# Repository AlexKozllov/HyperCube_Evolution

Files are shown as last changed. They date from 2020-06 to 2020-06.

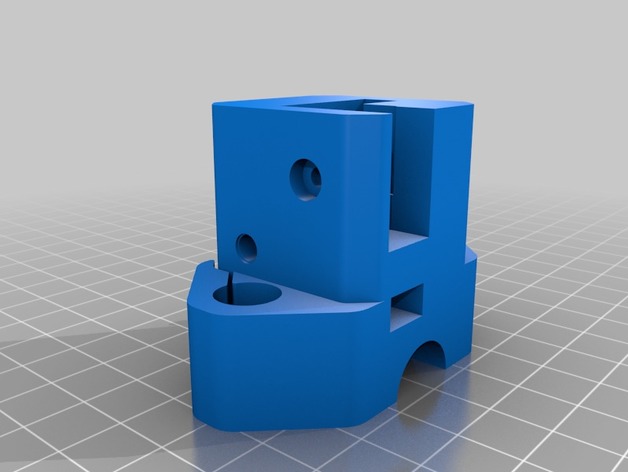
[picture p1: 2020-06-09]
images/1fd3070f1db277981bb9b3edc0ec5033_preview_featured.jpg

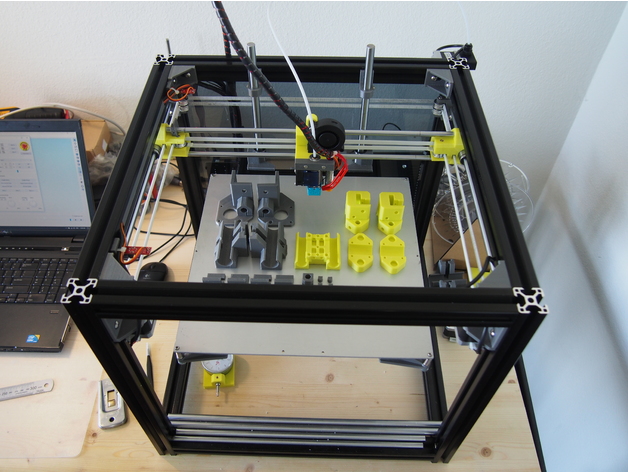
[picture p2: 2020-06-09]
images/2a23b4f932fd7e8579fa0705d6261fe2_preview_featured.JPG

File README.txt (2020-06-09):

                   .:                     :,                                          
,:::::::: ::`      :::                   :::                                          
,:::::::: ::`      :::                   :::                                          
.,,:::,,, ::`.:,   ... .. .:,     .:. ..`... ..`   ..   .:,    .. ::  .::,     .:,`   
   ,::    :::::::  ::, :::::::  `:::::::.,:: :::  ::: .::::::  ::::: ::::::  .::::::  
   ,::    :::::::: ::, :::::::: ::::::::.,:: :::  ::: :::,:::, ::::: ::::::, :::::::: 
   ,::    :::  ::: ::, :::  :::`::.  :::.,::  ::,`::`:::   ::: :::  `::,`   :::   ::: 
   ,::    ::.  ::: ::, ::`  :::.::    ::.,::  :::::: ::::::::: ::`   :::::: ::::::::: 
   ,::    ::.  ::: ::, ::`  :::.::    ::.,::  .::::: ::::::::: ::`    ::::::::::::::: 
   ,::    ::.  ::: ::, ::`  ::: ::: `:::.,::   ::::  :::`  ,,, ::`  .::  :::.::.  ,,, 
   ,::    ::.  ::: ::, ::`  ::: ::::::::.,::   ::::   :::::::` ::`   ::::::: :::::::. 
   ,::    ::.  ::: ::, ::`  :::  :::::::`,::    ::.    :::::`  ::`   ::::::   :::::.  
                                ::,  ,::                               ``             
                                ::::::::                                              
                                 ::::::                                               
                                  `,,`

https://www.thingiverse.com/thing:2254103
HyperCube Evolution by SCOTT_3D is licensed under the Creative Commons - Attribution license.
http://creativecommons.org/licenses/by/3.0/

# Summary

The HyperCube Evolution 3D Printer is a CoreXY printer inspired by the excellent HyperCube 3D Printer developed by Tech2C. The belt arrangement on that printer was the neatest CoreXY arrangement that I have seen.

I have leveraged the great work that Tech2C has done to refine his design and incorporated this with my own further development to reduce the number of printed parts and simplify the build.

Design goals for the HyperCube Evolution 3D Printer:

1. Increase the stiffness of the printer to further improve / reduce vibration artefacts.
	- 3030 extrusion used for the frame
	- 2020 extrusion used for the build platform frame
	- 8mm diameter X rails
	- 10mm diameter Y rails
	- 12mm diameter Z rails

2. Minimise the size of the printer for the chosen build volume.
	- Parametric CAD design in Autodesk Inventor
	- Excel spreadsheet provided to allow for customised printer size

The prototype printer, with a build volume of 300 x 300 x 300, met with all expectation but did show some small bed vibrations when printing at high speed due to the large bed and counter levered design. Therefore, two build options are available. A single Z axis version for smaller build platforms and a double Z axis version for larger beds or those wishing for a rock solid build platform.

The Evolution also features a quick attach X carriage to allow for interchangeable tools e.g. the extruder mount and a DTI mount for tramming the build platform.

More to come over the next few weeks as I'm awaiting parts for upgrade the prototype to use the double Z axis, and also the parts to convert my Geetech Prusa i3 into another HyperCube Evolution.

Facebook Group: https://www.facebook.com/groups/Hypercubeevolution/

<strong>Changelog:</strong>

20.04.2017 Configuration file updated, multiple size Bed Brackets added
22.04.2017 BOM added
23.04.2017 Introduction video added https://www.youtube.com/watch?v=1rctCsUGnX8&feature=youtu.be
23.04.2017 Added 4 variations of Y carriage to suit different combinations of 8mm and 10mm rails. Plus bearing clamps to suit. Note - current X carriage only suits LM8UU bearings. An adaptor will be needed to use 10mm bushings.
30.04.2017 Error found in spreadsheet which resulted in 10mm rails being 30mm too long. Version 1.2 uploaded.
09.05.2017 Version 1.1 Z Axis Linear Rail Bracket - Double Z - Left & Right. 
13.05.2017 Version 1.1 Z Nut Bracket - modified for easier assembly
13.05.2017 Z Nut Bracket for T10 leadscrew added
27.05.2017 Configuration file updated to include part print list (note that some part versions are still not available)
02.06.2017 Repetier configuration file uploaded
17.06.2017 40mm bed bracket added
17.06.2017 v1.1 versions of XY Stepper Mount and Idler Mount added which have slotted screw holes for different L brackets. v1.0 versions remain for those who don't need the slot.
17.06.2017 v1.1 of XY Stepper Mount and Idler Mount for 8mm diameter Y linear rails
18.06.2017 v1.4 configuration file added.. Thanks to Nicolas Harscoat for adding the shaft selector which then determines the part versions to be printed.
01.07.2017 CAD files uploaded for v1.0 as a pack and go. So the assembly should work. Note that some published parts are now v1.0+, but these files should get people going.
22.07.2017 Mounts for Full Graphic Controller added

<strong>BOM</strong>

<strong>Frame and linear guides</strong> – use the Excel spreadsheet to calculate the lengths required for your custom size.

3030 and 2020 extrusion
https://www.aliexpress.com/item/Customized-3030W-Aluminum-Extrusion-Profile-Free-cutting-in-any-Length-Black-Color/32799761497.html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

16 x L type bracket for 3030 extrusion
https://www.aliexpress.com/item/T-slot-L-type-90-degree-EU-standard-3030-aluminum-profile-Inside-corner-connector-bracket-with/32772827830.html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

8 x 3030 corner brackets
https://www.aliexpress.com/item/20pcs-lots-3030-corner-fitting-angle-aluminum-35-x-35-L-connector-bracket-fastener-match-use/32733275167.html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

<strong>Fasteners</strong>

M6 x 10 Button head screws - 6 off required for mounting of Stepper Motor Brackets and XY Idler Brackets

M5 x 10 Button head screws
https://www.aliexpress.com/item/100pcs-lot-M5-10-Bolt-A2-70-ISO7380-Button-Head-Socket-Screw-Bolt-SUS304-Stainless-Steel/32328885247.html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

M3 Socket head screws
https://www.aliexpress.com/item/Hex-Socket-Head-Cap-Screw-M3-Qty-90pcs-in-Box-Assortment-Kits-SUS-304-M3-4/32334431524.html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

100pcs M5 T Hammer Nuts for 3030 extrusion
https://www.aliexpress.com/item/100pcs-30-M5-hammer-nut-M5-block-t-slot-nuts-for-3030-aluminum-profile-extrusion-Slot/32688393400.html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

100pcs M5 T Hammer Nuts for 2020 extrusion
https://www.aliexpress.com/item/M5-T-Nut-Hammer-Nut-Aluminum-Connector-T-Fastener-Sliding-Nut-Nickel-Plated-Carbon-Steel-for/32619352982.html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

4 x 3mm dowel pins
https://www.aliexpress.com/item/GB119-304-Stainless-Steel-Cylindrical-Pin-Locating-Pin-M3-12/32789184323.html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

100pcs M3 5x5 Brass knurled insert
http://www.banggood.com/100pcs-M3x5x5mm-Metric-Threaded-Brass-Knurl-Round-Insert-Nuts-p-1050182.html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

<strong>Motors</strong>

1 or 2 x NEMA 17 Lead Screw M8 – length needs to be ~30mm longer than required Z travel, depending on nut type
https://www.aliexpress.com/item/New-3D-Printer-NEMA-17-Lead-Screw-300mm-Stepper-Motor-Z-Axis-3D-Printer-KIT-Step/32579962696.html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

3 x NEMA 17 42mm Stepper Motors
https://www.aliexpress.com/item/CE-certification-3pcs-4-lead-Nema17-Stepper-Motor-42-motor-D-shaft-motor-42BYGH-1-7A/32786907415.html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

<strong>Pulleys and Belts</strong>

2 x GT2 Timing Pulley (20 teeth) 5mm bore for 6mm belt
6 x GT2 Idler Pulley (20 teeth) 3mm bore
2 x GT2 Idler Pulley without teeth (20 teeth) 3mm bore
5m Polyurethane GT2 6mm belt
https://www.aliexpress.com/item/5-Meter-Polyurethane-GT2-6mm-Open-Timing-Belt-Width-6mm-GT2-2GT-Belt-For-3D-Printer/32616409980.html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

<strong>Linear Bearings</strong>

4 x LM12UU 12mm Linear Ball Bearings
4 x LM10UU 10mm Linear Ball Bearings or 2 x LM10LUU 10mm Long Linear Ball Bearings
4 x LM8UU 8mm Linear Ball Bearings

<strong>Heated Bed components</strong>

1 x Heated Bed 300x300
https://www.aliexpress.com/item/For-RepRap-3D-Prusa-Mendel-Printer-MK2A-300-300-3-0mm-Heater-Bed-RAMPS-1-4/32668984871.html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

4 or 6 x Levelling screws
https://www.aliexpress.com/item/3D-printer-Leveling-components-M3-screw-Leveling-spring-Leveling-knob-suite-free-shipping-M3-40-IMG/32562830096.html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

1 x 100kohm NTC3950 thermistor
https://www.aliexpress.com/item/1pcs-3d-printer-parts-100K-ohm-NTC-3950-Thermistors-with-cable-for-3D-Printer-Reprap-Mend/32489800025.html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

<strong>Control System</strong>

1 x 24V 400W power supply
https://www.aliexpress.com/item/Best-quality-24V-16-7A-400W-Switching-Power-Supply-Driver-for-LED-Strip-AC-100-240V/32318296978.html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

1 x RAMPS 1.4 with stepper drivers and display – NOTE: This board needs to be modified to run a 24V system. If you don’t then you will kill the Arduino Mega!
https://www.aliexpress.com/item/5pcs-A4988-Stepper-Driver-Module-with-Heatsink-1pcs-RAMPS-1-4-Controller-RAMPS1-4-LCD-12864/1869163278.html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

1 x RAMPS 1.4 fan extender module – use to run the 12V fans
https://www.aliexpress.com/item/Free-shipping-3D-Printer-Reprap-Ramps1-4-RRD-Fan-Extender-Max-20V-Fan-Expansion-Module/1804966614.html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

1 x DC-DC 24V-12V step down module
https://www.aliexpress.com/item/DC-DC-24V-18V-to-12V-3A-Step-Down-Module-MINI-Buck-Converter-Power-Supply-Circuit/32778770850.html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

1 x Arduino MEGA 2560
https://www.aliexpress.com/item/Mega-2560-CH340G-ATmega2560-16AU-Compatible-for-Arduino-Mega-2560/32517341214.html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

1 x Power expansion module (if needed)
https://www.aliexpress.com/item/for-3D-Printer-General-Add-on-Heated-Bed-Power-Expansion-Module-High-Power-Module-expansion-board/32706099435.html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

1 x 5V NPN M12 inductive sensor
https://www.aliexpress.com/item/M12-4mm-detection-5VDC-NPN-NO-LJ12A3-4-Z-BX-5V-cylinder-inductive-proximity-sensor-switch/32553311139.html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

4 x Optical end stops
https://www.aliexpress.com/item/2016-Newest-1-x-Optical-Endstop-End-Stop-Limit-Switch-Solution-for-3D-Printer-or-CNC/32656689805.html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,searchweb201602_3_10152_10065_10151_10068_10136_10137_10060_10138_10155_10062_10156_10134_10154_10056_10055_10054_10059_10099_10103_10102_10096_10148_10147_10052_10053_10142_10107_10050_10051_10084_10083_10080_10082_10081_10177_10110_10111_10112_10113_10114_10181_10037_10033_10032_10078_10079_10077_10073_10070_10123_10124,searchweb201603_2,afswitch_1,ppcSwitch_7&btsid=0a677c30-15c5-4511-bd9b-21cec7f98719&algo_expid=9458fd9d-18ca-4360-9463-2e064369527b-4&algo_pvid=9458fd9d-18ca-4360-9463-2e064369527b

<strong>Cable</strong>

5m x 24AWG 4 core UL2464 cable 
https://www.aliexpress.com/item/1M-UL-2464-2C-3C-4C-24-AWG-Multi-core-PVC-jacket-cable-Tinned-copper-wire/32781273770.html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

5m x 24AWG Red Black cable
https://www.aliexpress.com/item/IEKOV-5-M-Tinned-copper-24AWG-2-pin-Red-Black-cable-300V-PVC-insulated-wire-Electric/32649240375.html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

2m x 14AWG Silicone cable
https://www.aliexpress.com/item/14AWG-Flexible-Silicone-Wire-Cable-Soft-High-Temperature-Tinned-copper-UL-1M/32653995219.html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

5m x Servo extension cable
https://www.aliexpress.com/item/servo-JR-color-extension-cable-3p-line-futaba-jr-model-aircraft-model-wiring-Wholesale-30-core/32610086634.html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

Connectors for Stepper motors
https://www.aliexpress.com/item/20-Sets-Micro-JST-2-0-PH-6-Pin-Connector-plug-Male-Female-Crimps/32399923294.html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

# Print Settings

Printer: HyperCube Evolution
Rafts: No
Supports: Yes
Resolution: 0.2mm
Infill: 25 - 50%

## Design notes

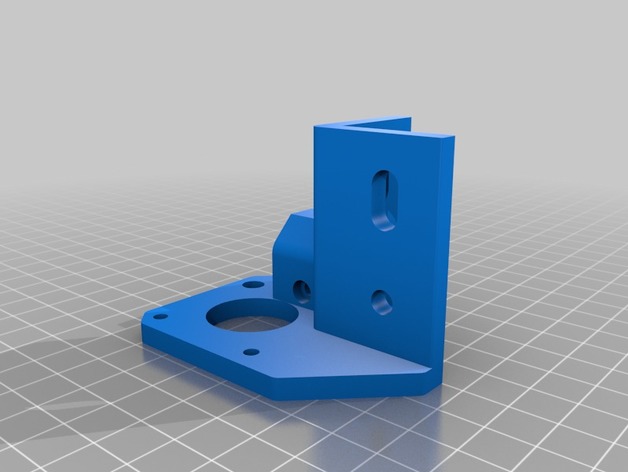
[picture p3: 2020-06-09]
images/ad542680490ceae1e7a6b8a47afab77d_preview_featured.jpg

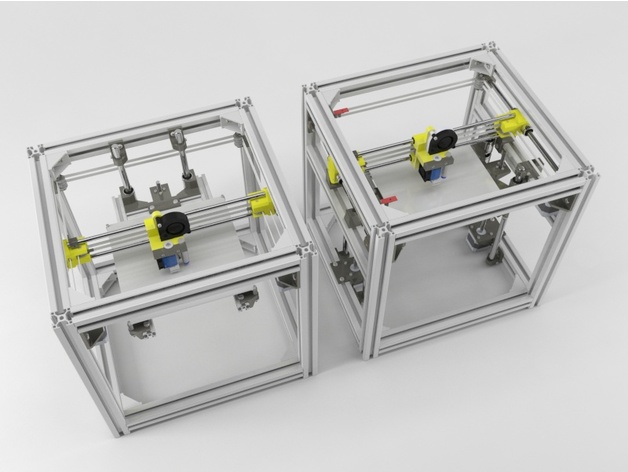
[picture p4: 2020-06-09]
images/4bb9b02da6ddbcb9a3b653392b5701b1_preview_featured.jpg

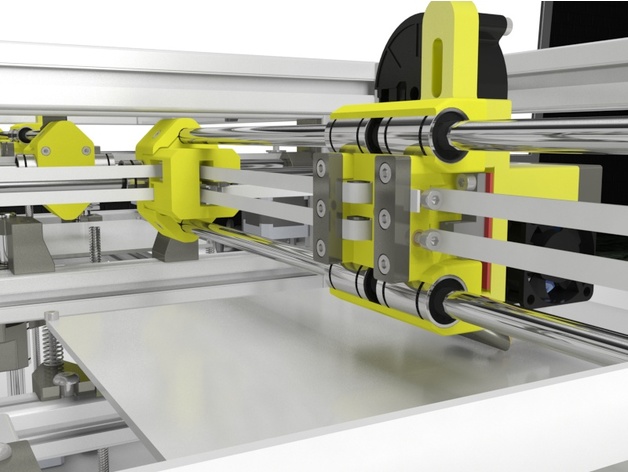
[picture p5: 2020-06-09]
images/7de90a276c049cf7b8a94b39b7449071_preview_featured.jpg

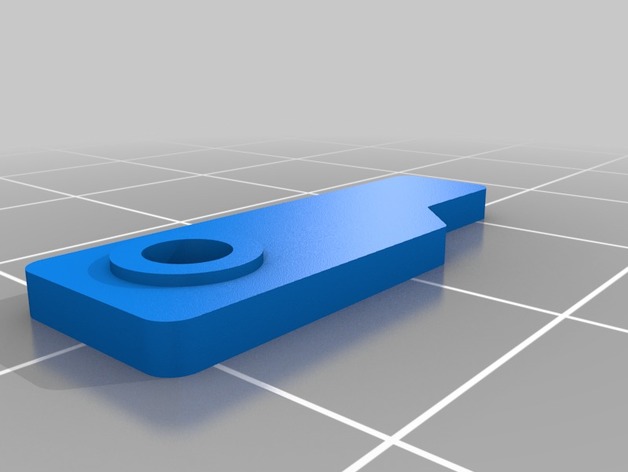
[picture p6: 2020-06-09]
images/36cfe11a45a6d4a730383c4952ed8a13_preview_featured.jpg

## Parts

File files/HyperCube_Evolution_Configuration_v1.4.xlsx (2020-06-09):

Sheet: Sheet1
Calculations - do not change
Parameter name | Equation | Unit | Design parameters
extrusion_size | 30 | mm
frame_width | 480 | mm | X Axis
frame_depth | 470 | mm | x_carriage_travel_min | 300
frame_height | 500 | mm | x_carriage_depth_rear | 14.5 | y offset from CL of x guides to rear of x carriage
platform_width | 328 | mm | x_carriage_width | 55
platform_depth | 328 | mm | x_carriage_nozzle_offset | 45.75 | y offset from CL of x guides to CL of nozzle
hole_spacing_width | 325 | mm | x_guide_spacing | 45
hole_spacing_depth | 325 | mm | x_guide_length | 450
bed_extrusion_size | 20 | mm | x_min_bed_offset | 30 |  | for dual z axis, the minimum distance between the z linear guide CL and the edge of the heated bed
bed_frame_width | 295 | mm |  |  |  |  |  | 325
bed_frame_depth | 400 | mm
bed_cl_y_offset | 216.25 | mm | Y Axis
T8_screw_length | 250 | mm | y_carriage_travel_min | 300
bracket_size | 15 | mm | y_min_offset | 31.5 | y min offset from inside of frame = width of XY motor mount
 |  |  | y_max_offset | 12 | y max offset from inside of frame = thickness of XY idler
 |  |  | y_carriage_depth | 58 | 2 x length of LM10UU bearing
 |  |  | y_carriage_width | 45 | from CL of Y axis guide to inside edge
 |  |  | y_guide_min_spacing | 445 | length of x axis guides
Build Platform | Equation | Unit | y_guide_length | 410
X width | 328 | mm
Y depth | 328 | mm | Z Axis
X spacing | 325 | mm | z_bed_travel_req | 300 |  | Note: lead screw should be this length + nut length
Y spacing | 325 | mm | z_nozzle_offset | 113.7 |  | Distance from top of frame to underside of nozzle
Bracket size | 15 | mm | z_bed_height | 68 |  | Distance from bottom of Z bearing holder to print surface
 |  |  | z_min_offset | 17 |  | Distance from bottom of frame to underside of Z bearing holder in Z Max position (bottom)
 |  |  | z_guide_diameter | 12 |  | Z linear guide diameter
 |  |  | z_guide_y_offset | 22 | CL offset from inside of frame
 |  |  | z_guide_length | 500
 |  |  |  |  |  | Single Z | Double Z
 |  |  | min_frame_width | 475 |  | 475 | 462
 |  |  | min_frame_depth | 463 |  | 463 | 388
 |  |  | min_frame_height | 498.7
 |  |  | min_bed_frame_width |  |  | 295 | 415
 |  |  | min_bed_frame_depth |  |  | 400 | 295
 |  |  | bed_mounting_width | 0 |  | 325 | 325
 |  |  | bed_mounting_depth | 0 |  | 325 | 325
 |  |  |  | 0

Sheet: Configuration
HyperCube
Evolution |  |  |  |  |  |  | Configurator | v1.4 | Build platform data
 |  |  |  |  |  |  |  |  |  | Dimensions |  | Mounting Holes
 |  |  |  |  |  |  |  |  | Name | X width | Y depth | X spacing | Y spacing
 |  |  |  |  |  |  |  |  | Mk2 Heat Bed | 214 | 214 | 210 | 210 | <- Minimum supported size. Do not change
 |  |  |  |  |  |  |  |  | Mk2A 300x300 (https://www.aliexpress.com/item/For-RepRap-3D-Prusa-Mendel-Printer-MK2A-300-300-3-0mm-Heater-Bed-RAMPS-1-4/32668984871.html) | 328 | 328 | 325 | 325
 |  |  |  |  |  |  |  |  | Custom | 300 | 300 | 290 | 290
Min. Build Volume / Travel |  |  |  |  | Build Platform |  | Z Axis
 | X | 300 | mm |  | Mk2A 300x300 | <- Select | Single | <- Select | Build platform mounting bracket data
 | Y | 300 | mm |  | Bed_bracket_15 | <- Select
 | Z | 300 | mm |  | Bracket selection Ok |  |  |  |  | Dimension
 |  |  |  |  |  |  |  |  | Name | offset
 |  |  |  |  | Shafts |  |  |  | Bed_bracket_15 | 15
 |  |  |  | X axis | Diam 8 | <- Select | Thanks to Nicolas Harscoat |  | Bed_bracket_20 | 20
 |  |  |  | Y axis | Diam 8 | <- Select | for the part selector |  | Bed_bracket_25 | 25
 |  |  |  | Z axis | Diam 12 | <- Select |  |  | Bed_bracket_30 | 30
 |  |  |  |  |  |  |  |  | Bed_bracket_45 | 45
 | BOM - Extrusions and linear guides
Item |  | Length | Unit | Qty | Note
3030 Extrusion |  | 420 | mm | 4 | Frame X extrusion
 |  | 410 | mm | 4 | Frame Y extrusion
 |  | 500 | mm | 4 | Frame Z extrusion
2020 Extrusion |  | 255 | mm | 1 | Bed frame X extrusion
 |  | 400 | mm | 2 | Bed frame Y extrusion
Diam 8 | Shaft | 450 | mm | 2 | X axis linear guide
Diam 8 | Shaft | 410 | mm | 2 | Y axis linear guide
Diam 12 | Shaft | 500 | mm | 2 | Z axis linear guide
Diam 8
Diam 10
Diam 12
Single
Double

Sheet: Print List
HyperCube | Printed part quantities
Evolution | All versions | X Axis Versions | Y Axis Versions | Z Axis Versions | Notes
Printed Part Name |  | Diam 8 | Diam 8 | Single
X-Carriage | 1
Belt_Clamp | 2
Belt_Tensioner | 4
Duct | 1
Extruder_Mount | 1
Retainer | 1
T_Slot_Cover | As needed
X_End_Stop_Flag | 2
XY_Idler_Mount_Left
XY_Idler_Mount_Left_yDia8 |  |  | 1
XY_Idler_Mount_Right
XY_Idler_Mount_Right_yDia8 |  |  | 1
XY_Stepper_Mount Left
XY_Stepper_Mount Left_yDia8 |  |  | 1
XY_Stepper_Mount Right
XY_Stepper_Mount Right_yDia8 |  |  | 1
Y_Carriage_Clamp_LM8UU |  |  | 2
Y_Carriage_Clamp_LM10UU
Y_Carriage_xDia8_LM8UU |  | 2
Y_Carriage_xDia8_LM10UU
Y_Carriage_xDia10_LM8UU
Y_Carriage_xDia10_LM10UU
Y_End_Stop_Bracket | 2
Y_End_Stop_Flag | 1
Z_Axis_Bearing_Holder |  |  |  | 2
Z_Axis_Linear_Rail_Bracket_-_Left |  |  |  | 2
Z_Axis_Linear_Rail_Bracket_-_Right |  |  |  | 2
Z_Axis_Linear_Rail_Bracket_-_Double_Z_-_Left
Z_Axis_Linear_Rail_Bracket_-_Double_Z_-_Right
Z_Motor_Mount |  |  |  | 1
Z_Nut_Braket |  |  |  | 1

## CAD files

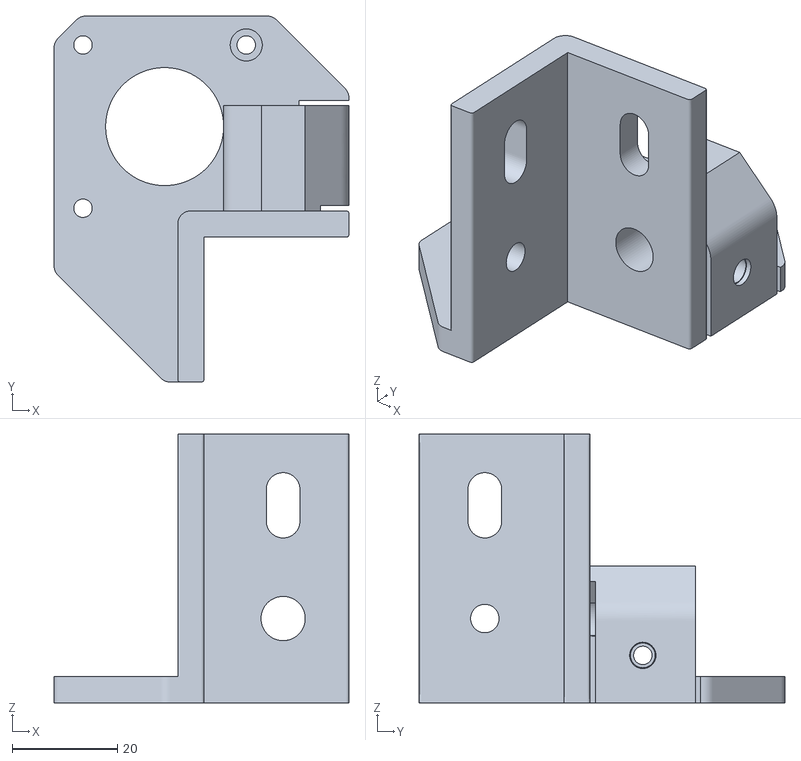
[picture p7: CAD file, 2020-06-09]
files/XY_Stepper_Mount_-_Right_yDia8_-_1.1.stl
56.0 x 69.5 x 51.0

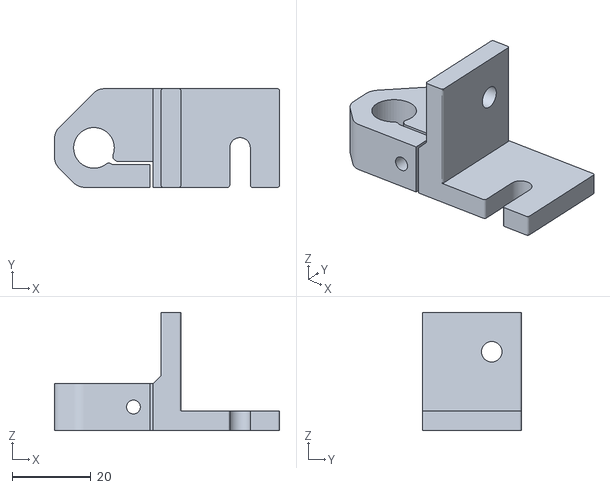
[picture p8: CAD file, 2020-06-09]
my_files/my_files_2_part/Z_Axis_Linear_Rail_Bracket_-_Right_2.0.stl
57.0 x 25.0 x 30.0

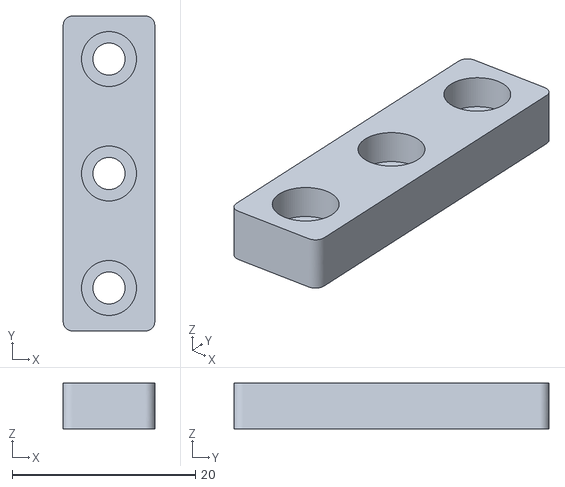
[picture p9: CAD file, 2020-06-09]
my_files/my_XYZ_2_part/Belt_Clamp_1.0.stl
10.0 x 34.4 x 5.00

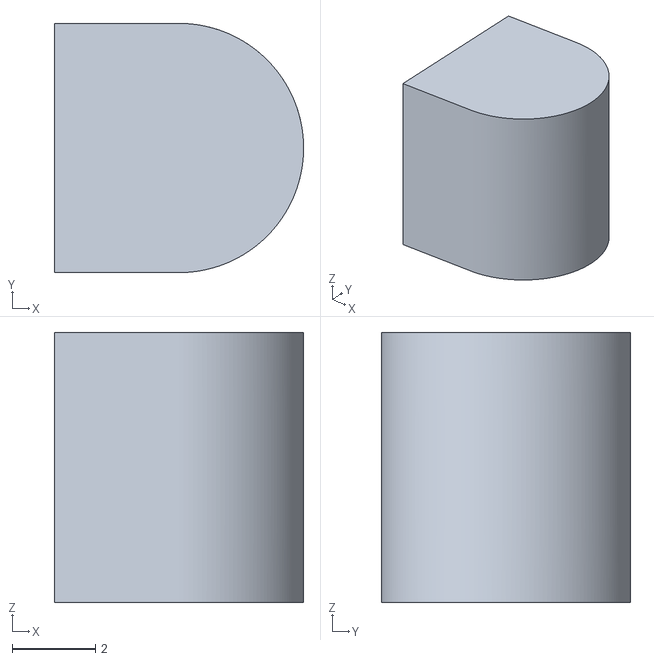
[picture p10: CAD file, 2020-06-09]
my_files/my_XYZ_3_part/Belt_Tensioner_1.0_______(_3X_).stl
6.00 x 6.00 x 6.50

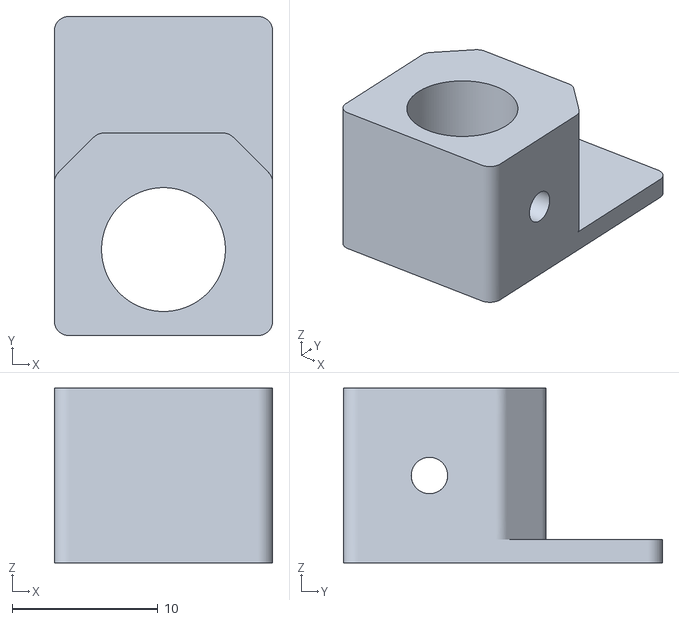
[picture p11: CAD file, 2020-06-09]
my_files/print_unchanged/Y_End_Stop_Flag_1.0.stl
15.0 x 21.9 x 12.0

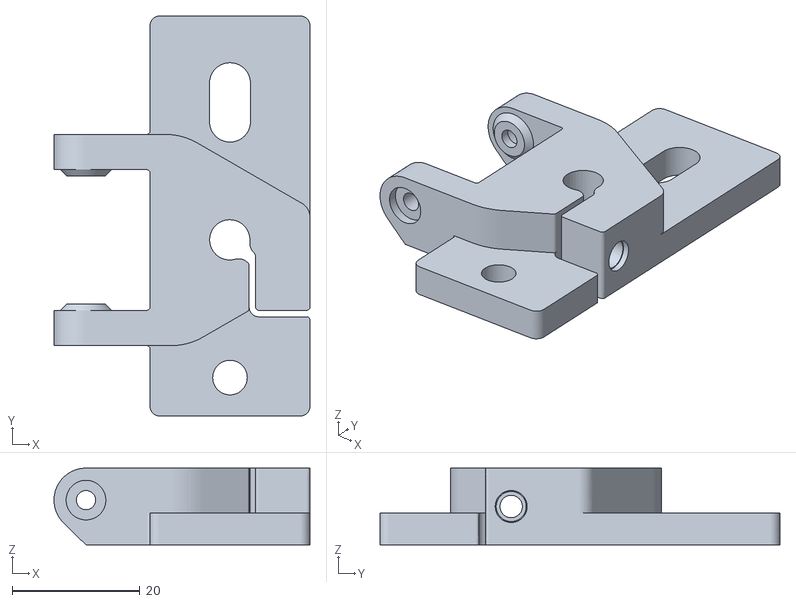
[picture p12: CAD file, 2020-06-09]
my_files/XY_Idler_Mount_-_Right_-_2.0.stl
40.0 x 62.5 x 12.0

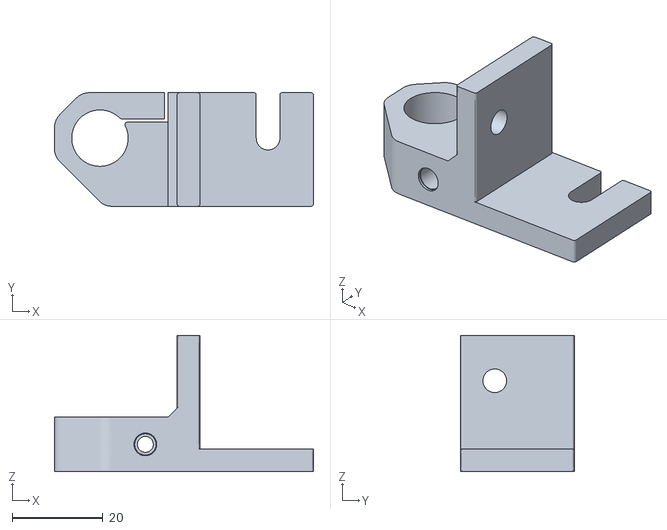
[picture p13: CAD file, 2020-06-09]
my_files/надо изменить/Z_Axis_Linear_Rail_Bracket_-_Left_1.0.stl
57.0 x 25.0 x 30.0

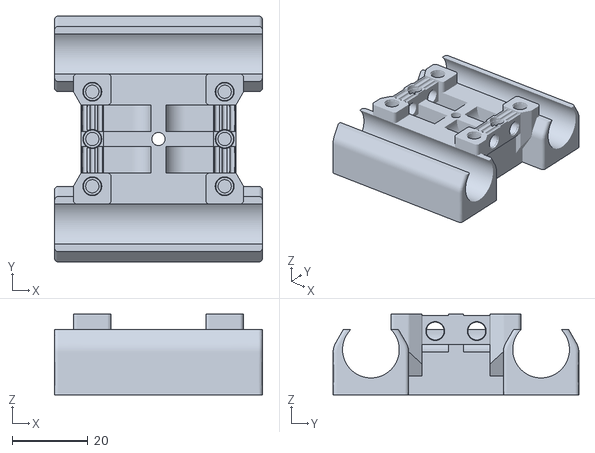
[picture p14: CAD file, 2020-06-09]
my_files/my_files_2_part/X_Carriage_1.0.stl
55.0 x 65.0 x 21.4

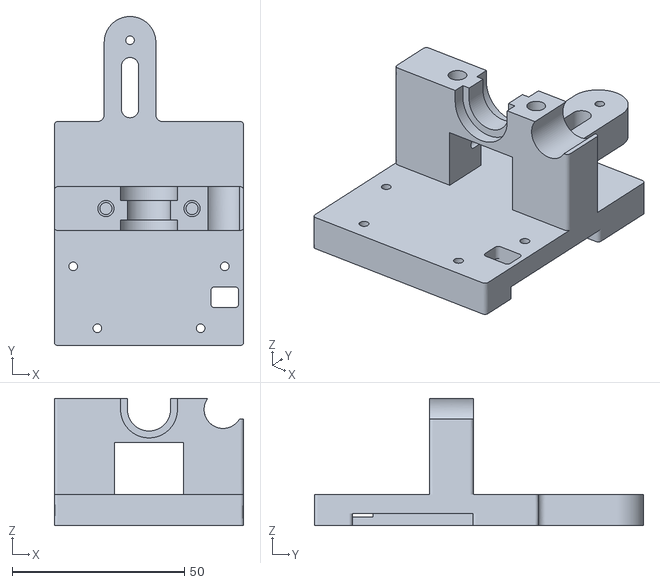
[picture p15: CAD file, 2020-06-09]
my_files/my_XYZ_2_part/Extruder_Mount_1.0.stl
55.0 x 95.5 x 37.0

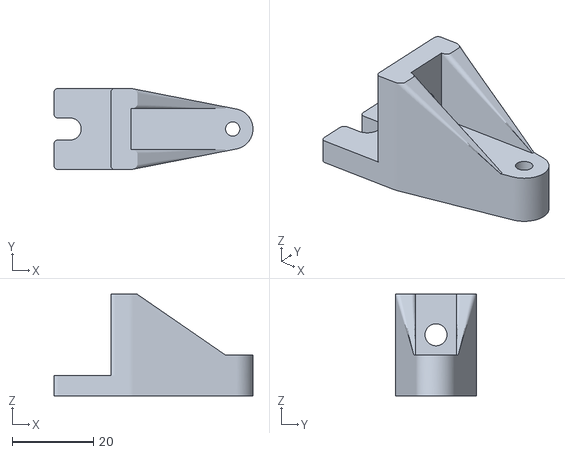
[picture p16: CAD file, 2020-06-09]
my_files/my_XYZ_3_part/Bed_Bracket_30_1.0_____(X3).stl
49.0 x 20.0 x 25.0

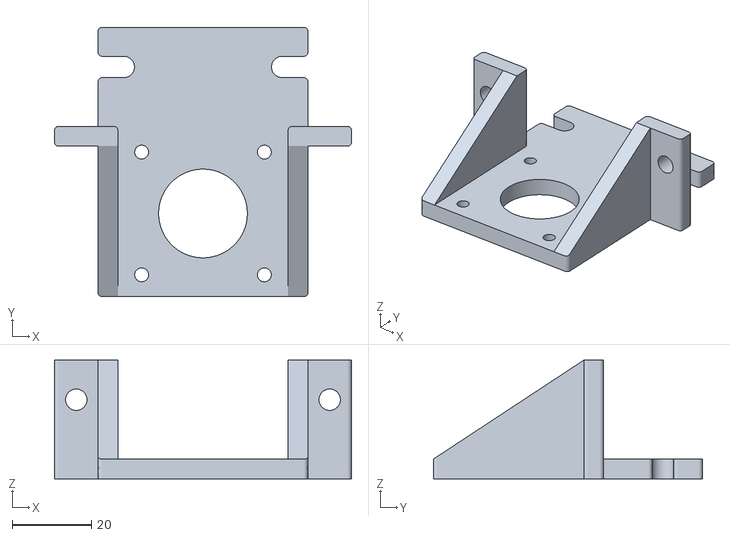
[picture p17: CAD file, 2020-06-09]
my_files/print_unchanged/Z_Motor_Mount_1.0.stl
75.0 x 68.0 x 30.0

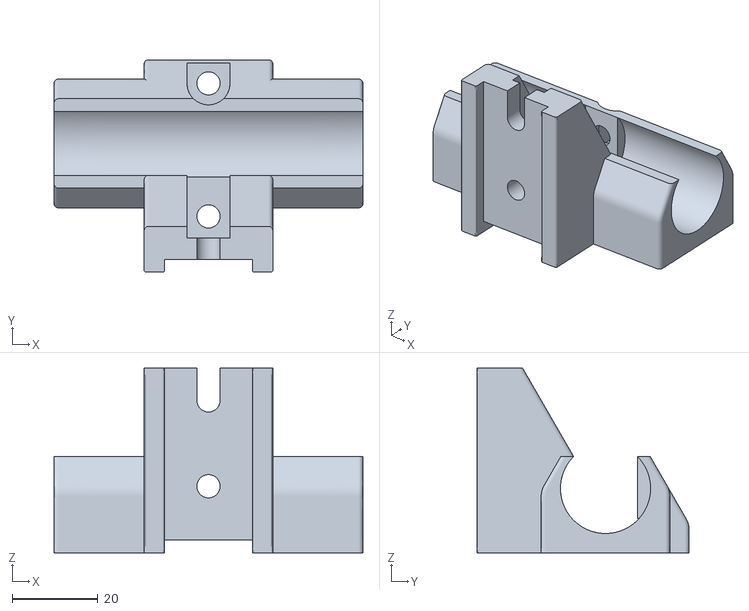
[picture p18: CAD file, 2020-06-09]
my_files/надо изменить/Z_Axis_Bearing_Holder_1.0.stl
72.0 x 49.5 x 43.0

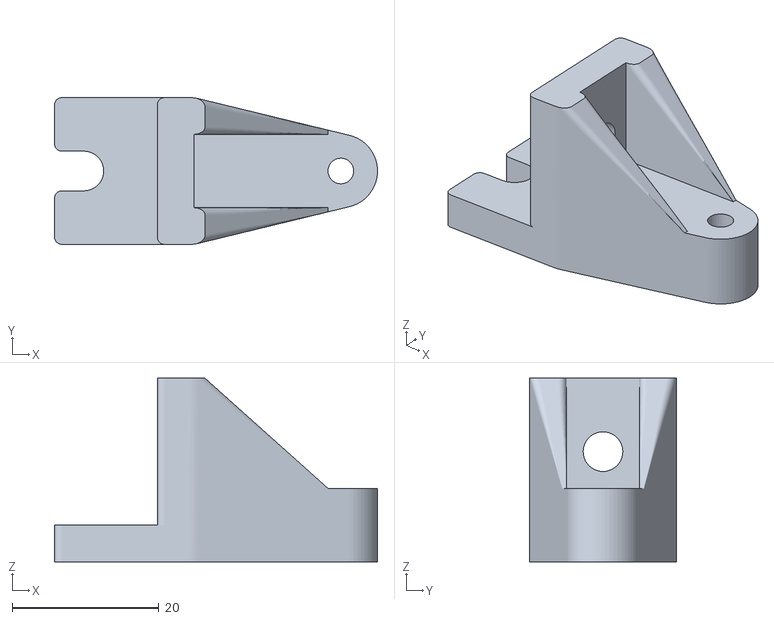
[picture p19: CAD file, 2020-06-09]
files/Bed_Bracket_25_1.0.stl
44.0 x 20.0 x 25.0

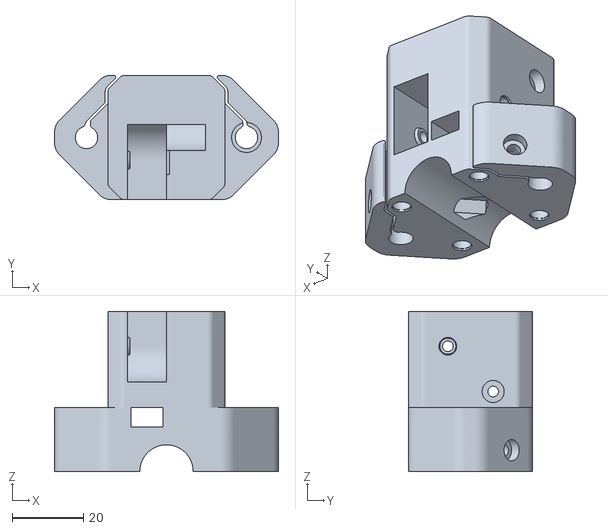
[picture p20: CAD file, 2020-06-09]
my_files/Y_Carriage_xDia8_LM8UU_2.0.stl
63.0 x 35.0 x 45.0

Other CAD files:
my_files/XY_Stepper_Mount_-_Right_-_2.0.stl
my_files/my_files_2_part/Z_Axis_Linear_Rail_Bracket_-_Left_2.0.stl
files/Bed_Bracket_15_1.0.stl
files/Bed_Bracket_20_1.0.stl
files/Bed_Bracket_40_1.0.stl
files/Bed_Bracket_45_1.0.stl
files/Duct_1.0.stl
files/FGSC_3030_Mount_-_Left_1.0.stl
files/FGSC_3030_Mount_-_Right_1.0.stl
files/HyperCube_Logo.dxf
files/Retainer_1.0.stl
files/T_Slot_Cover_1.0_-_250mm.stl
files/XY_Idler_Mount_-_Left_-_1.0.stl
files/XY_Idler_Mount_-_Left_yDia8_-_1.1.stl
files/XY_Idler_Mount_-_Right_-_1.0.stl
files/XY_Idler_Mount_-_Right_-_1.1.stl
files/XY_Idler_Mount_-_Right_yDia8_-_1.1.stl
files/XY_Idler_Mount_1.1.stl
files/XY_Stepper_Mount_-_Left_-_1.0.stl
files/XY_Stepper_Mount_-_Left_yDia8_-_1.1.stl
files/XY_Stepper_Mount_-_Right_-_1.0.stl
files/XY_Stepper_Mount_-_Right_-_1.1.stl
files/XY_Stepper_Mount_1.1.stl
files/X_End_Stop_Flag_1.0.stl
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

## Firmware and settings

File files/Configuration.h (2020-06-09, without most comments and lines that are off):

#define CONFIGURATION_H
#define NUM_EXTRUDER 1
#define MOTHERBOARD 33
#include "pins.h"
#undef FAN_PIN
#define FAN_PIN 11
#undef FAN_BOARD_PIN
#define FAN_BOARD_PIN -1
#define BOARD_FAN_SPEED 255
#define FAN_THERMO_PIN -1
#define FAN_THERMO_MIN_PWM 128
#define FAN_THERMO_MAX_PWM 255
#define FAN_THERMO_MIN_TEMP 45
#define FAN_THERMO_MAX_TEMP 60
#define FAN_THERMO_THERMISTOR_PIN -1
#define FAN_THERMO_THERMISTOR_TYPE 1
#define BLUETOOTH_SERIAL  -1
#define BLUETOOTH_BAUD  115200
#define MIXING_EXTRUDER 0
#define DRIVE_SYSTEM 1
#define XAXIS_STEPS_PER_MM 160.32
#define YAXIS_STEPS_PER_MM 160.32
#define ZAXIS_STEPS_PER_MM 400
#define EXTRUDER_FAN_COOL_TEMP 40
#define PDM_FOR_EXTRUDER 0
#define PDM_FOR_COOLER 0
#define DECOUPLING_TEST_MAX_HOLD_VARIANCE 20
#define DECOUPLING_TEST_MIN_TEMP_RISE 1
#define KILL_IF_SENSOR_DEFECT 0
#define RETRACT_ON_PAUSE 2
#define PAUSE_START_COMMANDS ""
#define PAUSE_END_COMMANDS ""
#define SHARED_EXTRUDER_HEATER 0
#define EXT0_X_OFFSET 0
#define EXT0_Y_OFFSET 0
#define EXT0_Z_OFFSET 0
#define EXT0_STEPS_PER_MM 100
#define EXT0_TEMPSENSOR_TYPE 8
#define EXT0_TEMPSENSOR_PIN TEMP_0_PIN
#define EXT0_HEATER_PIN HEATER_0_PIN
#define EXT0_STEP_PIN ORIG_E0_STEP_PIN
#define EXT0_DIR_PIN ORIG_E0_DIR_PIN
#define EXT0_INVERSE 0
#define EXT0_ENABLE_PIN ORIG_E0_ENABLE_PIN
#define EXT0_ENABLE_ON 0
#define EXT0_MIRROR_STEPPER 0
#define EXT0_STEP2_PIN ORIG_E0_STEP_PIN
#define EXT0_DIR2_PIN ORIG_E0_DIR_PIN
#define EXT0_INVERSE2 0
#define EXT0_ENABLE2_PIN ORIG_E0_ENABLE_PIN
#define EXT0_MAX_FEEDRATE 50
#define EXT0_MAX_START_FEEDRATE 20
#define EXT0_MAX_ACCELERATION 5000
#define EXT0_HEAT_MANAGER 1
#define EXT0_WATCHPERIOD 1
#define EXT0_PID_INTEGRAL_DRIVE_MAX 230
#define EXT0_PID_INTEGRAL_DRIVE_MIN 40
#define EXT0_PID_PGAIN_OR_DEAD_TIME 7
#define EXT0_PID_I 2
#define EXT0_PID_D 40
#define EXT0_PID_MAX 255
#define EXT0_ADVANCE_K 0
#define EXT0_ADVANCE_L 0
#define EXT0_ADVANCE_BACKLASH_STEPS 0
#define EXT0_WAIT_RETRACT_TEMP 150
#define EXT0_WAIT_RETRACT_UNITS 0
#define EXT0_SELECT_COMMANDS ""
#define EXT0_DESELECT_COMMANDS ""
#define EXT0_EXTRUDER_COOLER_PIN 6
#define EXT0_EXTRUDER_COOLER_SPEED 255
#define EXT0_DECOUPLE_TEST_PERIOD 12000
#define EXT0_JAM_PIN -1
#define EXT0_JAM_PULLUP 0
#define FEATURE_RETRACTION 1
#define AUTORETRACT_ENABLED 0
#define RETRACTION_LENGTH 3
#define RETRACTION_LONG_LENGTH 13
#define RETRACTION_SPEED 40
#define RETRACTION_Z_LIFT 0
#define RETRACTION_UNDO_EXTRA_LENGTH 0
#define RETRACTION_UNDO_EXTRA_LONG_LENGTH 0
#define RETRACTION_UNDO_SPEED 20
#define FILAMENTCHANGE_X_POS 0
#define FILAMENTCHANGE_Y_POS 0
#define FILAMENTCHANGE_Z_ADD  2
#define FILAMENTCHANGE_REHOME 1
#define FILAMENTCHANGE_SHORTRETRACT 5
#define FILAMENTCHANGE_LONGRETRACT 50
#define JAM_STEPS 220
#define JAM_SLOWDOWN_STEPS 320
#define JAM_SLOWDOWN_TO 70
#define JAM_ERROR_STEPS 500
#define JAM_MIN_STEPS 10
#define JAM_ACTION 1
#define RETRACT_DURING_HEATUP true
#define PID_CONTROL_RANGE 20
#define SKIP_M109_IF_WITHIN 2
#define SCALE_PID_TO_MAX 0
#define TEMP_HYSTERESIS 0
#define EXTRUDE_MAXLENGTH 160
#define NUM_TEMPS_USERTHERMISTOR0 0
#define USER_THERMISTORTABLE0 {}
#define NUM_TEMPS_USERTHERMISTOR1 0
#define USER_THERMISTORTABLE1 {}
#define NUM_TEMPS_USERTHERMISTOR2 0
#define USER_THERMISTORTABLE2 {}
#define GENERIC_THERM_VREF 5
#define GENERIC_THERM_NUM_ENTRIES 33
#define HEATER_PWM_SPEED 0
#define HAVE_HEATED_BED 1
#define HEATED_BED_MAX_TEMP 120
#define SKIP_M190_IF_WITHIN 3
#define HEATED_BED_SENSOR_TYPE 1
#define HEATED_BED_SENSOR_PIN TEMP_1_PIN
#define HEATED_BED_HEATER_PIN HEATER_1_PIN
#define HEATED_BED_SET_INTERVAL 5000
#define HEATED_BED_HEAT_MANAGER 0
#define HEATED_BED_PID_INTEGRAL_DRIVE_MAX 255
#define HEATED_BED_PID_INTEGRAL_DRIVE_MIN 80
#define HEATED_BED_PID_PGAIN_OR_DEAD_TIME   196
#define HEATED_BED_PID_IGAIN   33
#define HEATED_BED_PID_DGAIN 290
#define HEATED_BED_PID_MAX 255
#define HEATED_BED_DECOUPLE_TEST_PERIOD 300000
#define MIN_EXTRUDER_TEMP 150
#define MAXTEMP 275
#define MIN_DEFECT_TEMPERATURE -10
#define MAX_DEFECT_TEMPERATURE 290
#define SUPPORT_LASER 0
#define LASER_PIN -1
#define LASER_ON_HIGH 1
#define SUPPORT_CNC 0
#define CNC_WAIT_ON_ENABLE 300
#define CNC_WAIT_ON_DISABLE 0
#define CNC_ENABLE_PIN -1
#define CNC_ENABLE_WITH 1
#define CNC_DIRECTION_PIN -1
#define CNC_DIRECTION_CW 1
#define DEFAULT_PRINTER_MODE 0
#define ENDSTOP_PULLUP_X_MIN false
#define ENDSTOP_X_MIN_INVERTING false
#define MIN_HARDWARE_ENDSTOP_X true
#define ENDSTOP_PULLUP_Y_MIN false
#define ENDSTOP_Y_MIN_INVERTING false
#define MIN_HARDWARE_ENDSTOP_Y true
#define ENDSTOP_PULLUP_Z_MIN false
#define ENDSTOP_Z_MIN_INVERTING true
#define MIN_HARDWARE_ENDSTOP_Z true
#define ENDSTOP_PULLUP_X_MAX false
#define ENDSTOP_X_MAX_INVERTING false
#define MAX_HARDWARE_ENDSTOP_X true
#define ENDSTOP_PULLUP_Y_MAX false
#define ENDSTOP_Y_MAX_INVERTING false
#define MAX_HARDWARE_ENDSTOP_Y true
#define ENDSTOP_PULLUP_Z_MAX true
#define ENDSTOP_Z_MAX_INVERTING false
#define MAX_HARDWARE_ENDSTOP_Z false
#define max_software_endstop_r true
#define min_software_endstop_x false
#define min_software_endstop_y false
#define min_software_endstop_z false
#define max_software_endstop_x false
#define max_software_endstop_y false
#define max_software_endstop_z true
#define ENDSTOP_X_BACK_MOVE 5
#define ENDSTOP_Y_BACK_MOVE 5
#define ENDSTOP_Z_BACK_MOVE 2
#define ENDSTOP_X_RETEST_REDUCTION_FACTOR 3
#define ENDSTOP_Y_RETEST_REDUCTION_FACTOR 3
#define ENDSTOP_Z_RETEST_REDUCTION_FACTOR 3
#define ENDSTOP_X_BACK_ON_HOME 3
#define ENDSTOP_Y_BACK_ON_HOME 3
#define ENDSTOP_Z_BACK_ON_HOME 0
#define ALWAYS_CHECK_ENDSTOPS 0
#define X_ENABLE_ON 0
#define Y_ENABLE_ON 0
#define Z_ENABLE_ON 0
#define DISABLE_X 0
#define DISABLE_Y 0
#define DISABLE_Z 0
#define DISABLE_E 0
#define INVERT_X_DIR 0
#define INVERT_Y_DIR 0
#define INVERT_Z_DIR 1
#define X_HOME_DIR -1
#define Y_HOME_DIR -1
#define Z_HOME_DIR -1
#define X_MAX_LENGTH 300
#define Y_MAX_LENGTH 295
#define Z_MAX_LENGTH 200
#define X_MIN_POS 0
#define Y_MIN_POS 0
#define Z_MIN_POS 0
#define DISTORTION_CORRECTION 0
#define DISTORTION_CORRECTION_POINTS 5
#define DISTORTION_CORRECTION_R 100
#define DISTORTION_PERMANENT 1
#define DISTORTION_UPDATE_FREQUENCY 15
#define DISTORTION_START_DEGRADE 0.5
#define DISTORTION_END_HEIGHT 1
#define DISTORTION_EXTRAPOLATE_CORNERS 0
#define DISTORTION_XMIN 10
#define DISTORTION_YMIN 10
#define DISTORTION_XMAX 190
#define DISTORTION_YMAX 190
#define FEATURE_BABYSTEPPING 1
#define BABYSTEP_MULTIPLICATOR 1
#define DELTA_SEGMENTS_PER_SECOND_PRINT 180 // Move accurate setting for print moves
#define DELTA_SEGMENTS_PER_SECOND_MOVE 70 // Less accurate setting for other moves
#define EXACT_DELTA_MOVES 1
#define DELTA_HOME_ON_POWER 0
#define DELTASEGMENTS_PER_PRINTLINE 24
#define STEPPER_INACTIVE_TIME 360L
#define MAX_INACTIVE_TIME 0L
#define MAX_FEEDRATE_X 200
#define MAX_FEEDRATE_Y 200
#define MAX_FEEDRATE_Z 5
#define HOMING_FEEDRATE_X 40
#define HOMING_FEEDRATE_Y 40
#define HOMING_FEEDRATE_Z 2
#define HOMING_ORDER HOME_ORDER_XYZ
#define ZHOME_MIN_TEMPERATURE 0
#define ZHOME_HEAT_ALL 1
#define ZHOME_HEAT_HEIGHT 20
#define ZHOME_X_POS 999999
#define ZHOME_Y_POS 999999
#define ENABLE_BACKLASH_COMPENSATION 0
#define X_BACKLASH 0
#define Y_BACKLASH 0
#define Z_BACKLASH 0
#define RAMP_ACCELERATION 1
#define STEPPER_HIGH_DELAY 0
#define DIRECTION_DELAY 0
#define STEP_DOUBLER_FREQUENCY 12000
#define ALLOW_QUADSTEPPING 1
#define DOUBLE_STEP_DELAY 0 // time in microseconds
#define MAX_ACCELERATION_UNITS_PER_SQ_SECOND_X 1000
#define MAX_ACCELERATION_UNITS_PER_SQ_SECOND_Y 1000
#define MAX_ACCELERATION_UNITS_PER_SQ_SECOND_Z 100
#define MAX_TRAVEL_ACCELERATION_UNITS_PER_SQ_SECOND_X 1000
#define MAX_TRAVEL_ACCELERATION_UNITS_PER_SQ_SECOND_Y 1000
#define MAX_TRAVEL_ACCELERATION_UNITS_PER_SQ_SECOND_Z 100
#define INTERPOLATE_ACCELERATION_WITH_Z 0
#define ACCELERATION_FACTOR_TOP 100
#define MAX_JERK 10
#define MAX_ZJERK 0.3
#define PRINTLINE_CACHE_SIZE 16
#define MOVE_CACHE_LOW 10
#define LOW_TICKS_PER_MOVE 250000
#define EXTRUDER_SWITCH_XY_SPEED 100
#define DUAL_X_AXIS 0
#define FEATURE_TWO_XSTEPPER 0
#define X2_STEP_PIN   ORIG_E1_STEP_PIN
#define X2_DIR_PIN    ORIG_E1_DIR_PIN
#define X2_ENABLE_PIN ORIG_E1_ENABLE_PIN
#define FEATURE_TWO_YSTEPPER 0
#define Y2_STEP_PIN   ORIG_E1_STEP_PIN
#define Y2_DIR_PIN    ORIG_E1_DIR_PIN
#define Y2_ENABLE_PIN ORIG_E1_ENABLE_PIN
#define FEATURE_TWO_ZSTEPPER 0
#define Z2_STEP_PIN   ORIG_E1_STEP_PIN
#define Z2_DIR_PIN    ORIG_E1_DIR_PIN
#define Z2_ENABLE_PIN ORIG_E1_ENABLE_PIN
#define FEATURE_THREE_ZSTEPPER 0
#define Z3_STEP_PIN   ORIG_E2_STEP_PIN
#define Z3_DIR_PIN    ORIG_E2_DIR_PIN
#define Z3_ENABLE_PIN ORIG_E2_ENABLE_PIN
#define FEATURE_DITTO_PRINTING 0
#define USE_ADVANCE 0
#define ENABLE_QUADRATIC_ADVANCE 0
#define BAUDRATE 250000
#define ENABLE_POWER_ON_STARTUP 0
#define POWER_INVERTING 0
#define KILL_METHOD 1
#define ACK_WITH_LINENUMBER 1
#define WAITING_IDENTIFIER "wait"
#define ECHO_ON_EXECUTE 1
#define EEPROM_MODE 1
#undef PS_ON_PIN
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

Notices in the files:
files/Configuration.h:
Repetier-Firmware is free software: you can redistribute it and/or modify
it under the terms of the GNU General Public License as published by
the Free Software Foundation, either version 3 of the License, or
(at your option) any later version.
